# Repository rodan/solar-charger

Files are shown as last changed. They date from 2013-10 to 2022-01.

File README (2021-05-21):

12v lead-acid battery charger for 15-36V photovoltaic cells

 UNDER DEVELOPMENT

 source:       https://github.com/rodan/solar-charger 
 author:       Petre Rodan <2b4eda@subdimension.ro>
 license:      GNU GPLv3
 toolchain used: msp430-elf-gcc (Mitto Systems Limited - msp430-gcc 9.2.0.50) 9.2.0 linux

Features:
 - an MSP430F5510 uC controls all aspects of charging a 12v Pb battery
 - programming either via spy-bi-wire or usb (untested)
 - logging capability to a uSd card
 - backup 3v Li cell for keeping the RTC up-to-date
 - analog readout of battery voltage, input voltage, charge current, thermistor temperature, internal temperature
 - possibility to stop the charge if a condition is met
 - 8 status leds for verbose blinkiness
 - very low quiescent current

rev1 - used a LandStar charge controller that got replaced in rev3 with a PB137ACV ic
rev3 - 3V Li cell acts as bakup power for the uC, an SDcard is provided for logging
rev4 - SDcard is removed, 3V Li cell replaced by a 3.7v lipo + charging circuitry

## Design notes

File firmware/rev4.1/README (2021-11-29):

 source:       https://github.com/rodan/solar-charger 
 author:       Petre Rodan <2b4eda@subdimension.ro>
 license:      GNU GPLv3
 toolchain used: msp430-elf-gcc (Mitto Systems Limited - msp430-gcc 9.2.0.50) 9.2.0 linux

this firmware revision is to be used with rev4 hardware.

* How does this project work?

a photovoltaic cell and a lipo battery provide redundant power to the microcontroller. 

if the PV voltage is above 6.2V (1.5s after being enabled) then it means that it can provide 4mA of current to feed the buck circuitry and it becomes the primary power for the BQ24072 powerpath IC and the entire board. otherwise the lipo 1-cell provides power to the board.

if the PV voltage is above 6.2V (1.5s after charging circuit was enabled) then it means that it can provide the ~700mW of power needed to charge the lipo cell.

a RTC-based alarm will trigger an irrigation relay once per day.

this setup described above can be reached if J1 ties VIN to the center tap, J2 is open, a jumper ties VBAT to Q3's drain (to skip the 12V charger) and the following compoments are not populated: R32, R23, R27, D2, IC1, C26, C27.

otherwise a lead-acid 12V battery can also be charged. this option is not currently covered by the firmware.

* Compiling the project

the toolchain used for this project is provided by TI [1]. the rest of the tools needed by the Makefile in order to compile the project are readily available in most Linux distributions.
make sure to 'git clone' the msp430 reference libraries [2] (or provide a symlink to them) to /opt/atlas430

use the following commands:

 ln -s "/FIXTHIS/reference_libs_msp430" /opt/atlas430

 make
    builds the entire project with the MSP430F5510 target. all the resulting objects and the elf binary will be inside the './build/MSP430F5510' subdirectory

 make install
    takes ./build/MSP430F5510/main.elf and tries to flash it. this needs the mspdebug application, an ezfet-1.2 or msp-fet programmer connected to the target board.

 make scan-build
    optional static scan provided by Clang (if installed)

 make cppcheck
    optional static scan provided by Cppcheck (if installed)

[1] https://www.ti.com/tool/MSP430-GCC-OPENSOURCE
[2] https://github.com/rodan/atlas430

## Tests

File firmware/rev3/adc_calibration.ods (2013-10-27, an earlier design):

 | 22.7dC ambient
Port 6.0
 | vin | vsense | adc | vref | (vin/vsense)*100/1023
 | 5.013 | 0.691 | 294 | 2.4044 | 0.7092
 | 6.06 | 0.8372 | 351 | 2.4400 | 0.7076
 | 7.015 | 0.9676 | 407 | 2.4321 | 0.7087
 | 8.03 | 1.108 | 466 | 2.4324 | 0.7084
 | 9.016 | 1.2439 | 522 | 2.4378 | 0.7085
 | 10.025 | 1.3833 | 580 | 2.4399 | 0.7084
 | 11.03 | 1.5228 | 639 | 2.4379 | 0.7080
 | 12.001 | 1.656 | 695 | 2.4375 | 0.7084
 | 13.04 | 1.8 | 755 | 2.4389 | 0.7082
 | 14.07 | 1.9432 | 816 | 2.4361 | 0.7078
 | 15.02 | 2.073 | 870 | 2.4376 | 0.7083
 | 16.08 | 2.22 | 932 | 2.4368 | 0.7080
mean values |  |  |  | 2.4343 | 0.7083
 |  |  | VREF_2_5_6_0 | 2.4343
 |  |  | DIV_BAT | 0.7083
Port 6.1
 | vin | vsense | adc | vref | (vin/vsense)*100/1023
 | 5.013 | 0.4884 | 206 | 2.4254 | 1.0033
 | 6.06 | 0.5902 | 246 | 2.4544 | 1.0037
 | 7.015 | 0.6826 | 285 | 2.4502 | 1.0046
 | 8.03 | 0.7817 | 326 | 2.4530 | 1.0042
 | 9.016 | 0.8775 | 365 | 2.4594 | 1.0044
 | 10.025 | 0.9758 | 407 | 2.4527 | 1.0043
 | 11.03 | 1.074 | 448 | 2.4525 | 1.0039
 | 12.001 | 1.1679 | 487 | 2.4533 | 1.0045
 | 13.04 | 1.2696 | 529 | 2.4552 | 1.0040
 | 14.07 | 1.3707 | 571 | 2.4557 | 1.0034
 | 15.02 | 1.4625 | 609 | 2.4567 | 1.0039
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

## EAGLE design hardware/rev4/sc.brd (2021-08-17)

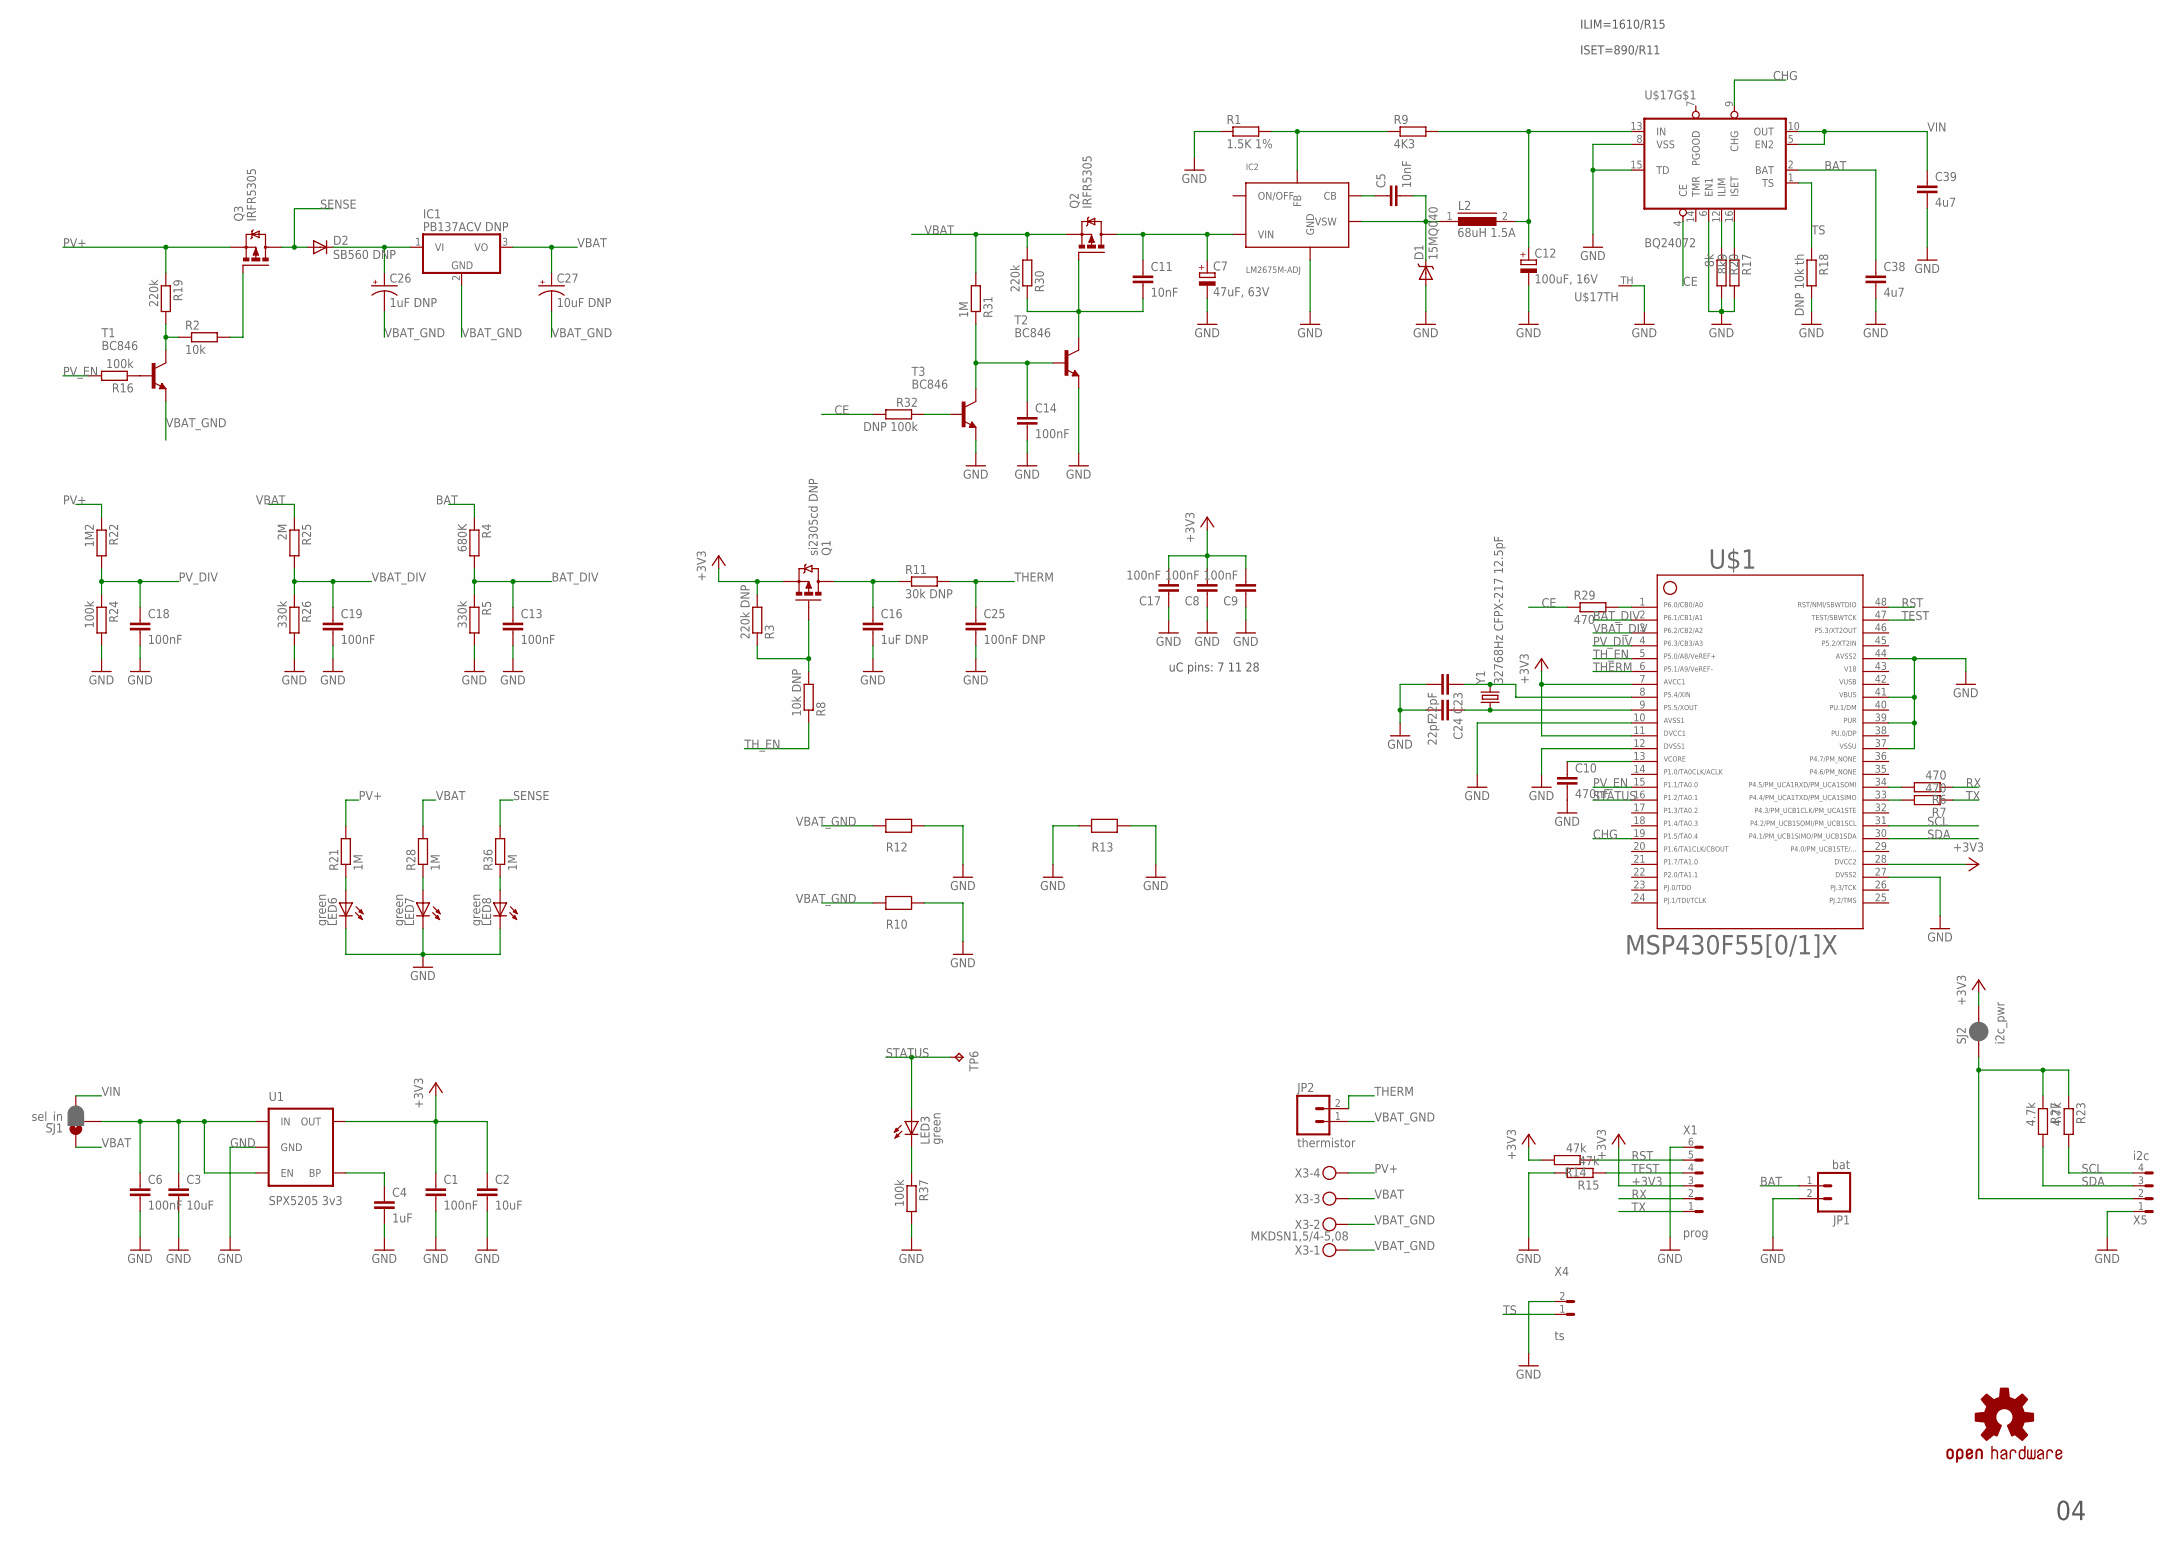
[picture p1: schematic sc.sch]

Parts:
C1, C6, C8, C9, C13, C14, C17, C18, C19: 100nF; C0805
C2, C3: 10uF; C1206
C4: 1uF; C0805
C5, C11: 10nF; C0805
C7: 47uF, 63V; PANASONIC_F
C10: 470nF; C0805
C12: 100uF, 16V; PANASONIC_D
C16: 1uF DNP; C0805
C23, C24: 22pF; C0805
C25: 100nF DNP; C0805
C26: 1uF DNP; PANASONIC_D
C27: 10uF DNP; PANASONIC_D
C38, C39: 4u7; C1206
D1: 15MQ040; SMA-DIODE
D2: SB560 DNP; C1702-05
IC1: PB137ACV DNP; TO220V
IC2: LM2675M-ADJ; SO-08
JP1: bat; 1X02
JP2: thermistor; 1X02
L2: 68uH 1.5A; DR125
LED3: green; CHIPLED_0805
LED6, LED7, LED8: green; CHIP-LED0805
Q1: si2305cd DNP; SOT23-3_POWER@1
Q2, Q3: IRFR5305; D-PAK_TO252AA
R1: 1.5K 1%; R0805W
R2: 10k; R0805W
R3: 220k DNP; R0805W
R4: 680K; R0805W
R5, R26: 330k; R0805W
R6, R7, R29: 470; R0805W
R8: 10k DNP; R0805W
R9: 4K3; R0805W
R10, R12, R13: 0R_0805; R0805W
R11: 30k DNP; R0805W
R14, R15: 47k; R0805W
R16, R24, R37: 100k; R0805W
R17: 8k9; R0805W
R18: DNP 10k th; R0805W
R19, R30: 220k; R0805W
R20: 8k; R0805W
R21, R28, R31, R36: 1M; R0805W
R22: 1M2; R0805W
R23, R27: 4.7k; R0805W
R25: 2M; R0805W
R32: DNP 100k; R0805W
SJ1: sel_in; PAD-JUMPER-3-2OF3_NC_BY_PASTE_YES_SILK_FULL_BOX
SJ2: i2c_pwr; PAD-JUMPER-2-NC_BY_PASTE_YES_SILK
T1, T2, T3: BC846; SOT23
TP6: TPTP12R; TP12R
U1: SPX5205 3v3; SOT23-5
U$1: F55[0/1]X---PT48; PT48
U$7: OSHW-LOGOM; OSHW-LOGO-M
U$17: BQ24072; S-PVQFN-N16
X1: prog; 0530480610
X3: MKDSN1,5/4-5,08
X4: ts; 0530480210
X5: i2c; 0530480401
Y1: 32768Hz CFPX-217 12.5pF; CRYSTAL-SMD-3.2X1.5

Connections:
42: U$1.42
43: U$1.43
46: U$1.46
+3V3: C1.1, C2.1, C8.2, C9.2, C17.2, Q1.2 (S), R3.2, R14.2, SJ2.2, U1.5 (OUT), U$1.7, U$1.11, U$1.28, X1.3 (4)
BAT: C38.1, JP1.1, R4.1, U$17.2 (BAT)
BAT_DIV: C13.1, R4.2, R5.1, U$1.2
CE: R29.1, R32.2, U$17.4 (CE)
CHG: U$1.19, U$17.9 (CHG)
GND: C1.2, C2.2, C3.2, C4.2, C6.2, C7.-, C8.1, C9.1, C10.2, C12.-, C13.2, C14.2, C16.2, C17.1, C18.2, C19.2, C23.2, C24.2, C25.2, C38.2, C39.2, D1.A, IC2.6 (GND), JP1.2, LED6.C, LED7.C, LED8.C, R1.1, R5.2, R10.2, R12.2, R13.1, R13.2, R15.2, R17.2, R18.2, R20.2, R24.2, R26.2, R37.2, T2.2 (E), T3.2 (E), U1.2 (GND), U$1.10, U$1.12, U$1.27, U$1.37, U$1.39, U$1.41, U$1.44, U$17.6 (EN1), U$17.8 (VSS), U$17.15 (TD), U$17.TH, X1.6 (1), X4.2 (1), X5.1 (4)
unnamed: C16.1, Q1.3 (D), R11.1
unnamed: C4.1, U1.4 (BP)
unnamed: R16.1, T1.1 (B)
unnamed: IC2.4 (FB), R1.2, R9.1
unnamed: R2.1, R19.2, T1.3 (C)
unnamed: C10.1, U$1.13
unnamed: C3.1, C6.1, SJ1.2, U1.1 (IN), U1.3 (EN)
unnamed: C26.+, D2.C, IC1.1 (VI)
unnamed: C5.2, D1.C, IC2.8 (VSW), L2.1
unnamed: C5.1, IC2.1 (CB)
unnamed: R6.2, U$1.34
unnamed: LED6.A, R21.1
unnamed: R7.2, U$1.33
unnamed: Q1.1 (G), R3.1, R8.2
unnamed: C12.+, L2.2, R9.2, U$17.13 (IN)
unnamed: C11.2, Q2.1 (G), R30.1, T2.3 (C)
unnamed: R23.1, R27.1, SJ2.1, X5.2 (3)
unnamed: LED7.A, R28.1
unnamed: R29.2, U$1.1
unnamed: C14.1, R31.1, T2.1 (B), T3.3 (C)
unnamed: R32.1, T3.1 (B)
unnamed: LED8.A, R36.1
unnamed: C24.1, U$1.9, Y1.P$1 (1)
unnamed: C23.1, U$1.8, Y1.P$2 (2)
unnamed: Q3.1 (G), R2.2
unnamed: R17.1, U$17.16 (ISET)
unnamed: R20.1, U$17.12 (ILIM)
unnamed: LED3.C, R37.1
unnamed: C7.+, C11.1, IC2.7 (VIN), Q2.4 (D)
PV+: Q3.3 (S), R19.1, R21.2, R22.1, X3.4
PV_DIV: C18.1, R22.2, R24.1, U$1.4
PV_EN: R16.2, U$1.15
RST: R14.1, U$1.48, X1.5 (2)
RX: R6.1, X1.2 (5)
SCL: R23.2, U$1.31, X5.4 (1)
SDA: R27.2, U$1.30, X5.3 (2)
SENSE: D2.A, Q3.4 (D), R36.2
STATUS: LED3.A, TP6.TP, U$1.16
TEST: R15.1, U$1.47, X1.4 (3)
THERM: C25.1, JP2.2, R11.2, U$1.6
TH_EN: R8.1, U$1.5
TS: R18.1, U$17.1 (TS), X4.1 (2)
TX: R7.1, X1.1 (6)
VBAT: C27.+, IC1.3 (VO), Q2.3 (S), R25.1, R28.2, R30.2, R31.2, SJ1.1, X3.3
VBAT_DIV: C19.1, R25.2, R26.1, U$1.3
VBAT_GND: C26.-, C27.-, IC1.2 (GND), JP2.1, R10.1, R12.1, T1.2 (E), X3.1, X3.2
VIN: C39.1, SJ1.3, U$17.5 (EN2), U$17.10 (OUT)

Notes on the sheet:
uC pins: 7 11 28
ILIM=1610/R15
ISET=890/R11

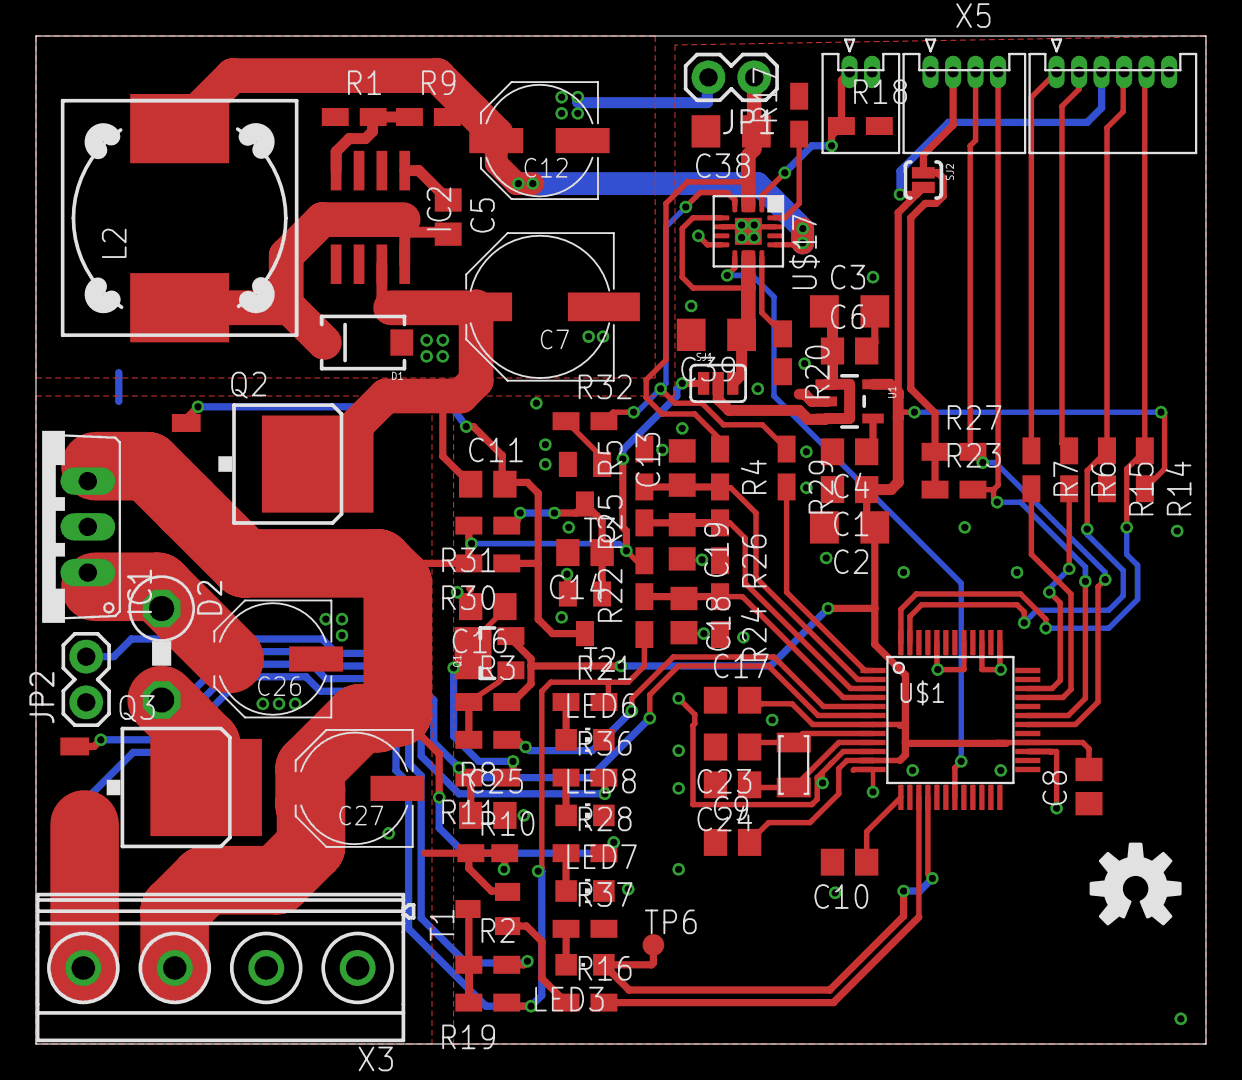
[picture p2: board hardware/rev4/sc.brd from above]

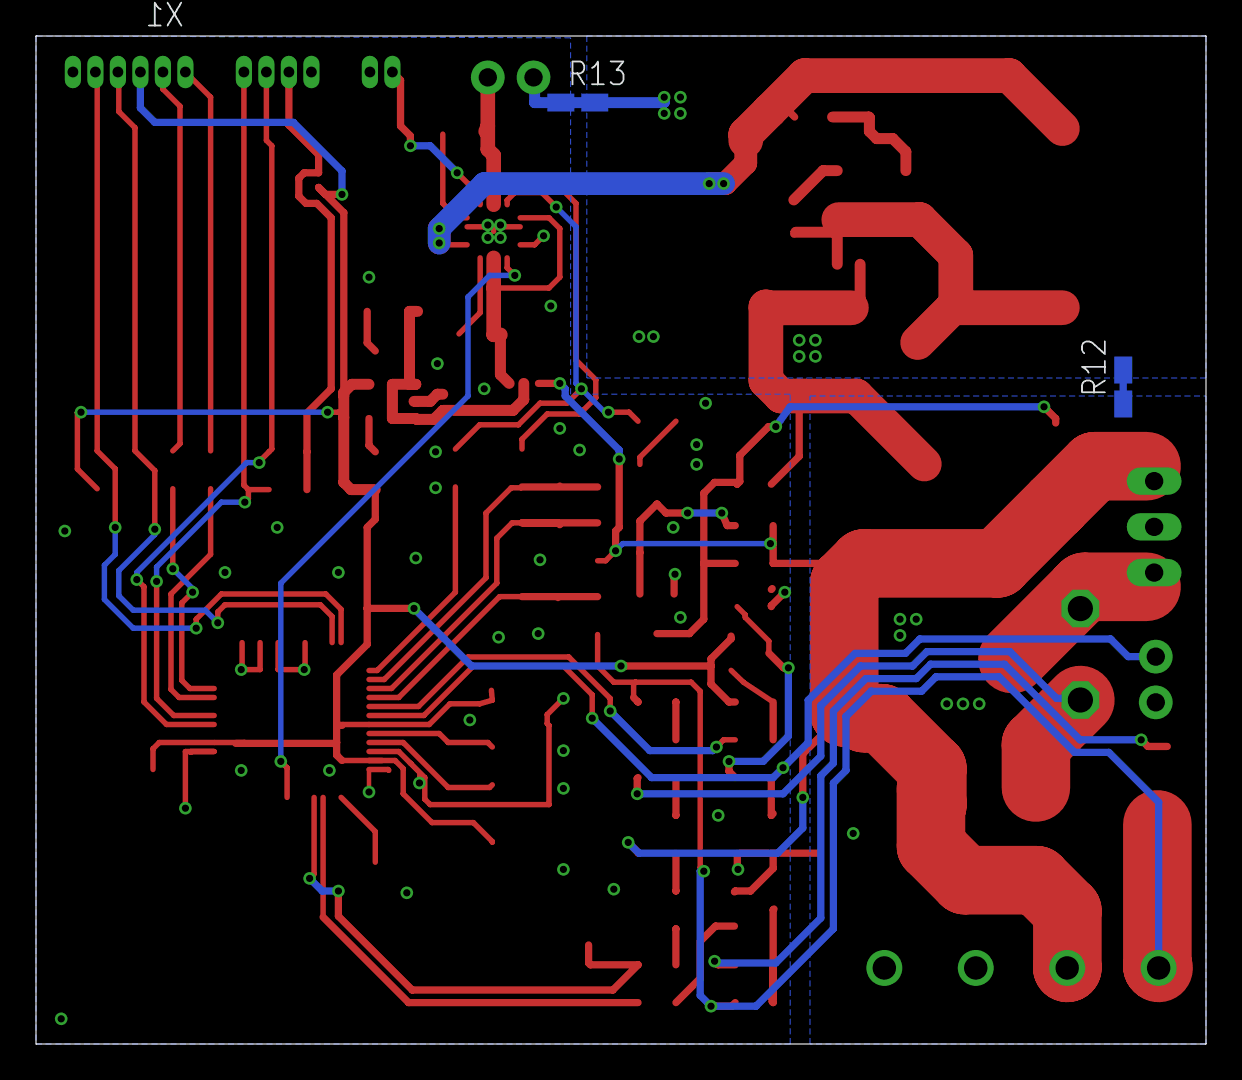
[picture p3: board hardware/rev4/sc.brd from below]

Board: 2 copper layers, 65.0 x 56.0 mm, 88 parts (2 on the bottom side), 53 nets.

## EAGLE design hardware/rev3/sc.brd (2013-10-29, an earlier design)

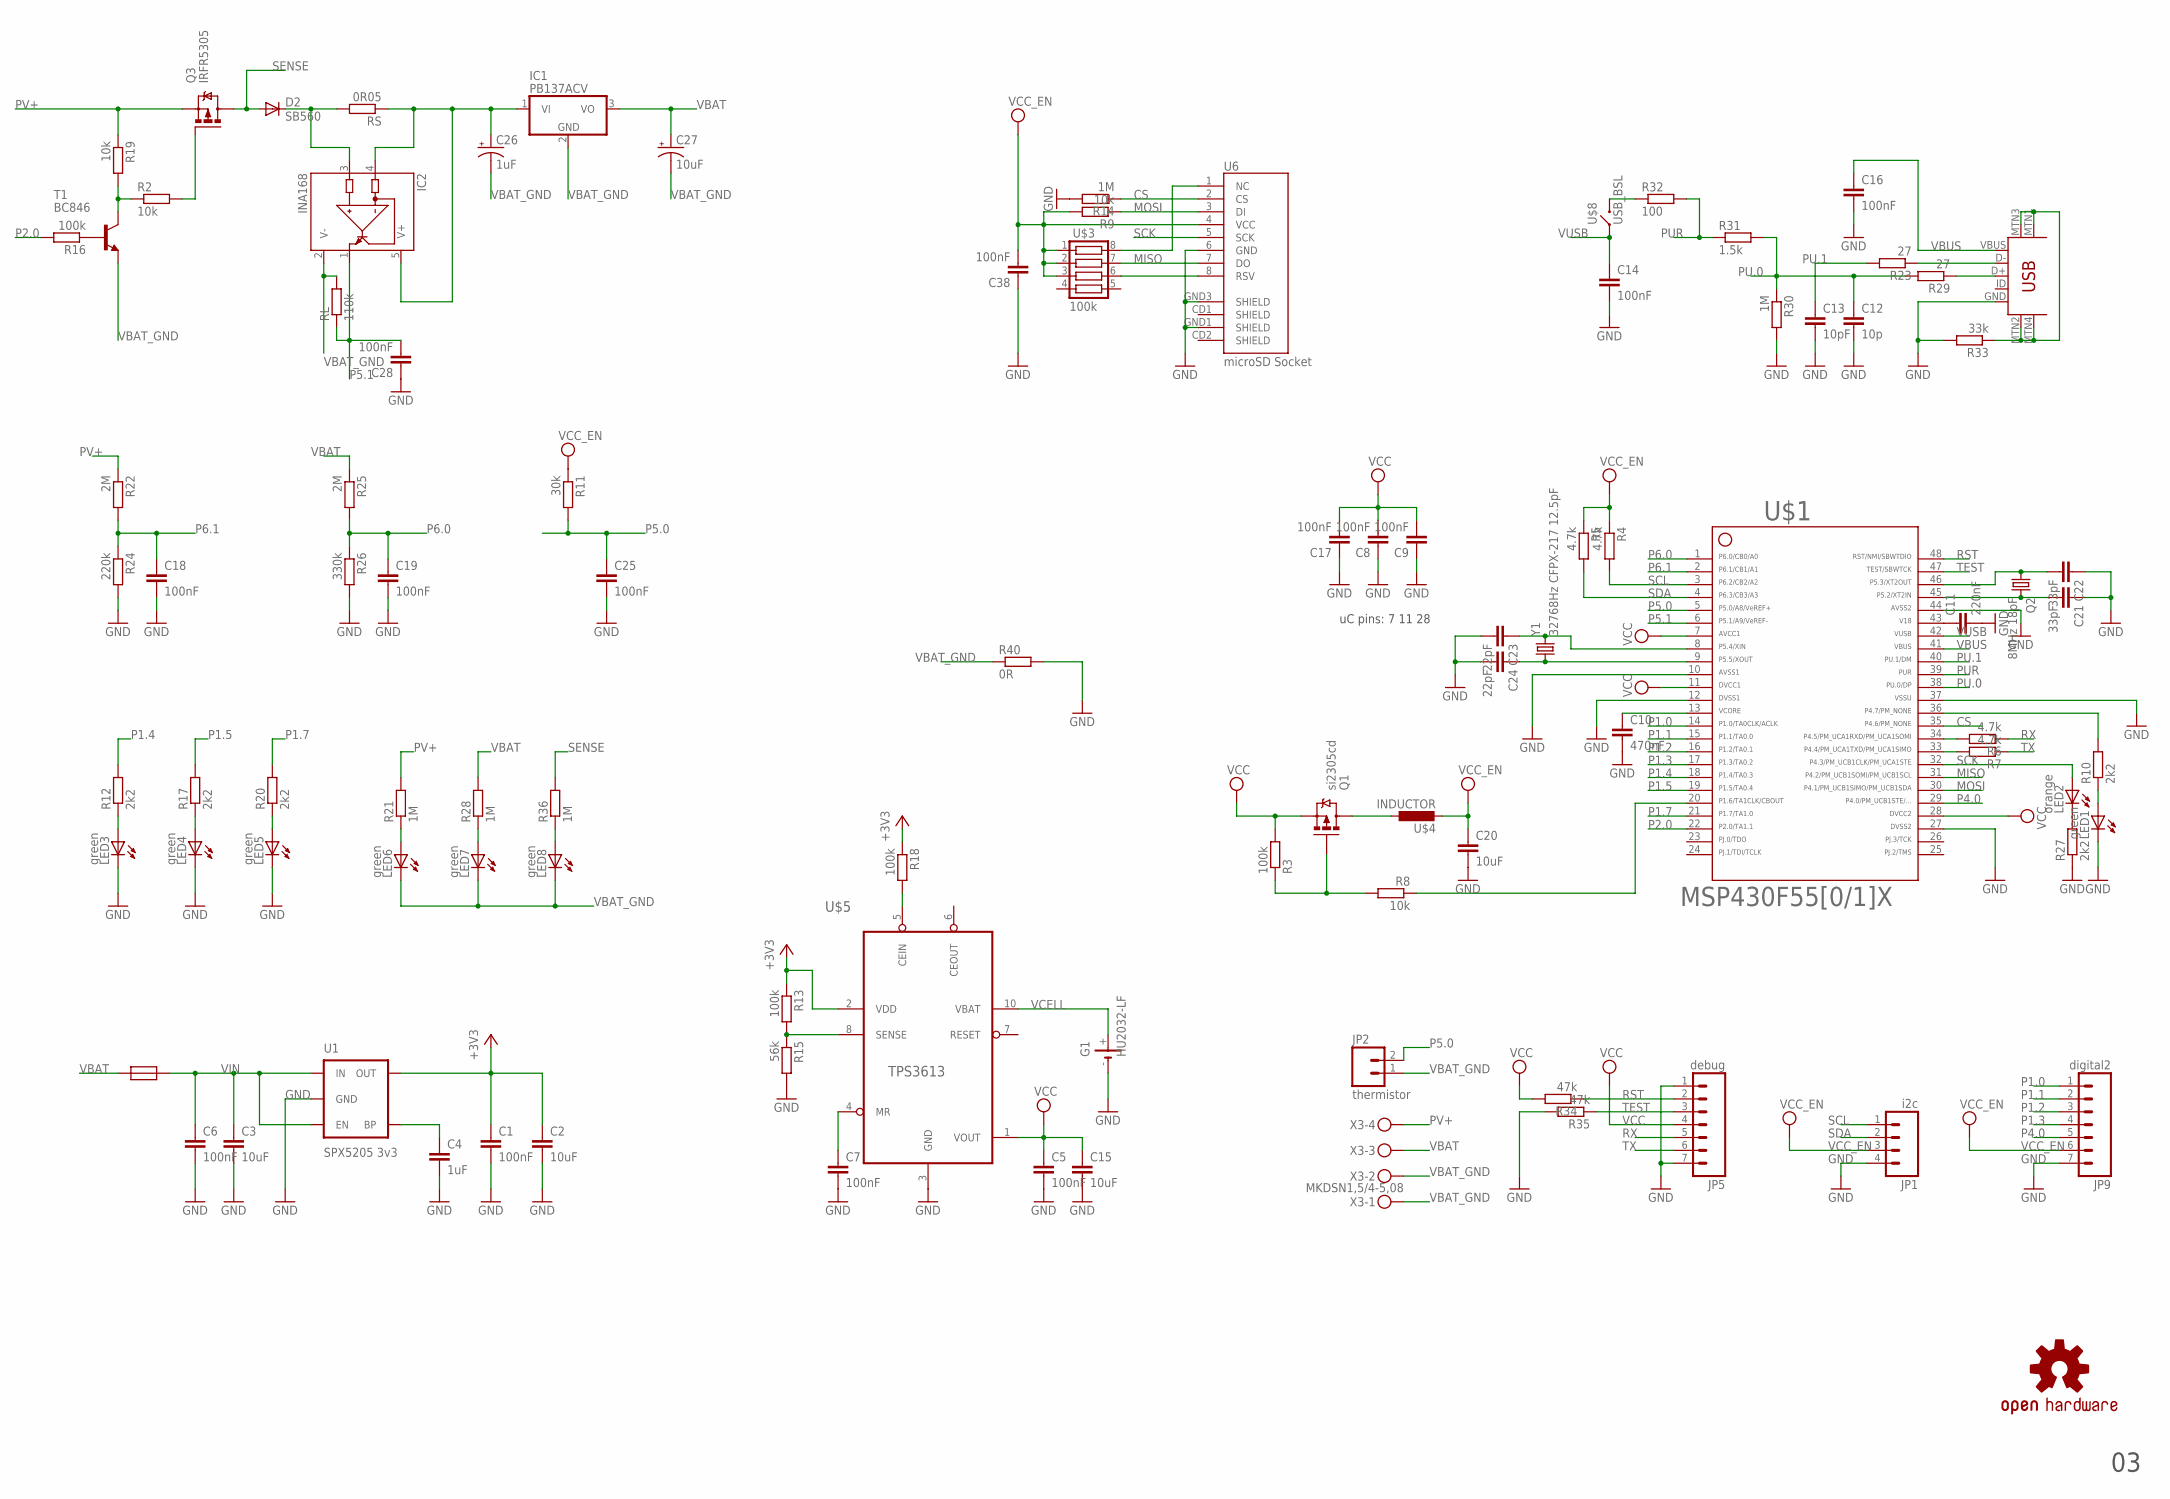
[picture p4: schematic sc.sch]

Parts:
C1, C5, C6, C7, C8, C9, C14, C16, C17, C18, C19, C25, C28, C38: 100nF; C0805
C2, C3, C15, C20: 10uF; C1206
C4: 1uF; C0805
C10: 470nF; C0805
C11: 220nF; C0805
C12: 10p; C0805
C13: 10pF; C0805
C21, C22: 33pF; C0805
C23, C24: 22pF; C0805
C26: 1uF; PANASONIC_D
C27: 10uF; PANASONIC_D
D2: SB560; C1702-05
G1: HU2032-LF
IC1: PB137ACV; TO220V
IC2: INA168; SOT23-5
JP1: i2c; 1X04
JP2: thermistor; 1X02
JP5: debug; 1X07
JP9: digital2; 1X07
LED1, LED3, LED4, LED5, LED6, LED7, LED8: green; CHIP-LED0805
LED2: orange; CHIP-LED0805
Q1: si2305cd; SOT23-3_POWER
Q2: 8MHz 18pF; CRYSTAL_5X3.2
Q3: IRFR5305; D-PAK_TO252AA
R2, R8, R9, R19: 10k; R0805W
R3, R13, R16, R18: 100k; R0805W
R4, R5, R6, R7: 4.7k; R0805W
R10, R12, R17, R20, R27: 2k2; R0805W
R11: 30k; R0805W
R14, R21, R28, R30, R36: 1M; R0805W
R15: 56k; R0805W
R22, R25: 2M; R0805W
R23, R29: 27; R0805W
R24: 220k; R0805W
R26: 330k; R0805W
R31: 1.5k; R0805W
R32: 100; R0805W
R33: 33k; R0805W
R34, R35: 47k; R0805W
R40: 0R; R0805W
RL: 110k; R0805W
RS: 0R05; TO220ACS
T1: BC846; SOT23
U1: SPX5205 3v3; SOT23-5
U6: microSD Socket; MICRO-SD-SOCKET-PP
U$1: F55[0/1]X---PT48; PT48
U$2: RESETTABLE; 1210
U$3: 100k; YC164
U$4: INDUCTOR; L0805W
U$5: TPS3613; MSOP_10P
U$6: USB-MINIB-5PIN; USB-MINIB
U$7: OSHW-LOGOM; OSHW-LOGO-M
U$8: USB_BSL; 6X3.5_TACTILE_SW
X3: MKDSN1,5/4-5,08
Y1: 32768Hz CFPX-217 12.5pF; CRYSTAL-SMD-3.2X1.5

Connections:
+3V3: C1.1, C2.1, R13.1, R18.1, U1.5 (OUT), U$5.2 (VDD)
CS: R14.1, U6.2 (CS), U$1.35
EN: R8.1, U$1.20
GND: C1.2, C2.2, C3.2, C4.2, C5.2, C6.2, C7.2, C8.1, C9.1, C10.2, C11.2, C12.2, C13.2, C14.2, C15.2, C16.2, C17.1, C18.2, C19.2, C20.2, C21.1, C22.1, C23.2, C24.2, C25.2, C28.1, C38.1, G1.-, JP1.4, JP5.1, JP5.7, JP9.7, LED1.C, LED3.C, LED4.C, LED5.C, R14.2, R15.2, R24.2, R26.2, R27.1, R30.2, R33.2, R35.2, R40.2, U1.2 (GND), U6.6 (GND), U6.GND1 (SHIELD), U6.GND3 (SHIELD), U$1.10, U$1.12, U$1.27, U$1.37, U$1.44, U$5.3 (GND), U$6.GND
LED: R10.2, U$1.36
MISO: U6.7 (DO), U$1.31, U$3.7
MOSI: R9.1, U6.3 (DI), U$1.30
unnamed: LED1.A, R10.1
unnamed: C4.1, U1.4 (BP)
unnamed: R16.1, T1.1 (B)
unnamed: U6.1 (NC), U$3.8
unnamed: R2.1, R19.2, T1.3 (C)
unnamed: C10.1, U$1.13
unnamed: C11.1, U$1.43
unnamed: LED3.A, R12.1
unnamed: C26.+, IC1.1 (VI), IC2.4 (IN-), IC2.5 (V+), RS.A (1)
unnamed: R6.2, U$1.34
unnamed: LED6.A, R21.1
unnamed: R7.2, U$1.33
unnamed: Q1.1 (G), R3.1, R8.2
unnamed: LED4.A, R17.1
unnamed: LED5.A, R20.1
unnamed: C22.2, Q2.P$1 (1), U$1.46
unnamed: LED7.A, R28.1
unnamed: R13.2, R15.1, U$5.8 (SENSE)
unnamed: C7.1, U$5.4 (MR)
unnamed: R18.2, U$5.5 (CEIN)
unnamed: R29.1, U$6.D+
unnamed: C21.2, Q2.P$2 (2), U$1.45
unnamed: LED8.A, R36.1
unnamed: C24.1, U$1.9, Y1.P$1 (1)
unnamed: C23.1, U$1.8, Y1.P$2 (2)
unnamed: U6.8 (RSV), U$3.6
unnamed: Q3.1 (G), R2.2
unnamed: R23.1, U$6.D-
unnamed: D2.C, IC2.3 (IN+), RS.C (2)
unnamed: R32.1, U$8.2
unnamed: R33.1, U$6.MTN1 (MTN2), U$6.MTN2 (MTN3), U$6.MTN3 (MTN1), U$6.MTN4
unnamed: Q1.3 (D), U$4.1
unnamed: LED2.C, R27.2
P1.0: JP9.1, U$1.14
P1.1: JP9.2, U$1.15
P1.2: JP9.3, U$1.16
P1.3: JP9.4, U$1.17
P1.4: R12.2, U$1.18
P1.5: R17.2, U$1.19
P1.7: R20.2, U$1.21
P2.0: R16.2, U$1.22
P4.0: JP9.5, U$1.29
P5.0: C25.1, JP2.2, R11.2, U$1.5
P5.1: C28.2, IC2.1 (OUT), RL.1, U$1.6
P6.0: C19.1, R25.2, R26.1, U$1.1
P6.1: C18.1, R22.2, R24.1, U$1.2
PU.0: C12.1, R29.2, R30.1, R31.2, U$1.38
PU.1: C13.1, R23.2, U$1.40
PUR: R31.1, R32.2, U$1.39
PV+: Q3.3 (S), R19.1, R21.2, R22.1, X3.4
RST: JP5.2, R34.1, U$1.48
RX: JP5.5, R6.1
SCK: LED2.A, U6.5 (SCK), U$1.32
SCL: JP1.1, R4.2, U$1.3
SDA: JP1.2, R5.2, U$1.4
SENSE: D2.A, Q3.4 (D), R36.2
TEST: JP5.3, R35.1, U$1.47
TX: JP5.6, R7.1
VBAT: C27.+, IC1.3 (VO), R25.1, R28.2, U$2.P$1, X3.3
VBAT_GND: C26.-, C27.-, IC1.2 (GND), IC2.2 (V-), JP2.1, LED6.C, LED7.C, LED8.C, R40.1, RL.2, T1.2 (E), X3.1, X3.2
VBUS: C16.1, U$1.41, U$6.VBUS
VCC: C5.1, C8.2, C9.2, C15.1, C17.2, JP5.4, Q1.2 (S), R3.2, R34.2, U$1.7, U$1.11, U$1.28, U$5.1 (VOUT)
VCC_EN: C20.1, C38.2, JP1.3, JP9.6, R4.1, R5.1, R9.2, R11.1, U6.4 (VCC), U$3.1, U$3.2, U$3.3, U$4.2
VCELL: G1.+, U$5.10 (VBAT)
VIN: C3.1, C6.1, U1.1 (IN), U1.3 (EN), U$2.P$2
VUSB: C14.1, U$1.42, U$8.1

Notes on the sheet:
uC pins: 7 11 28

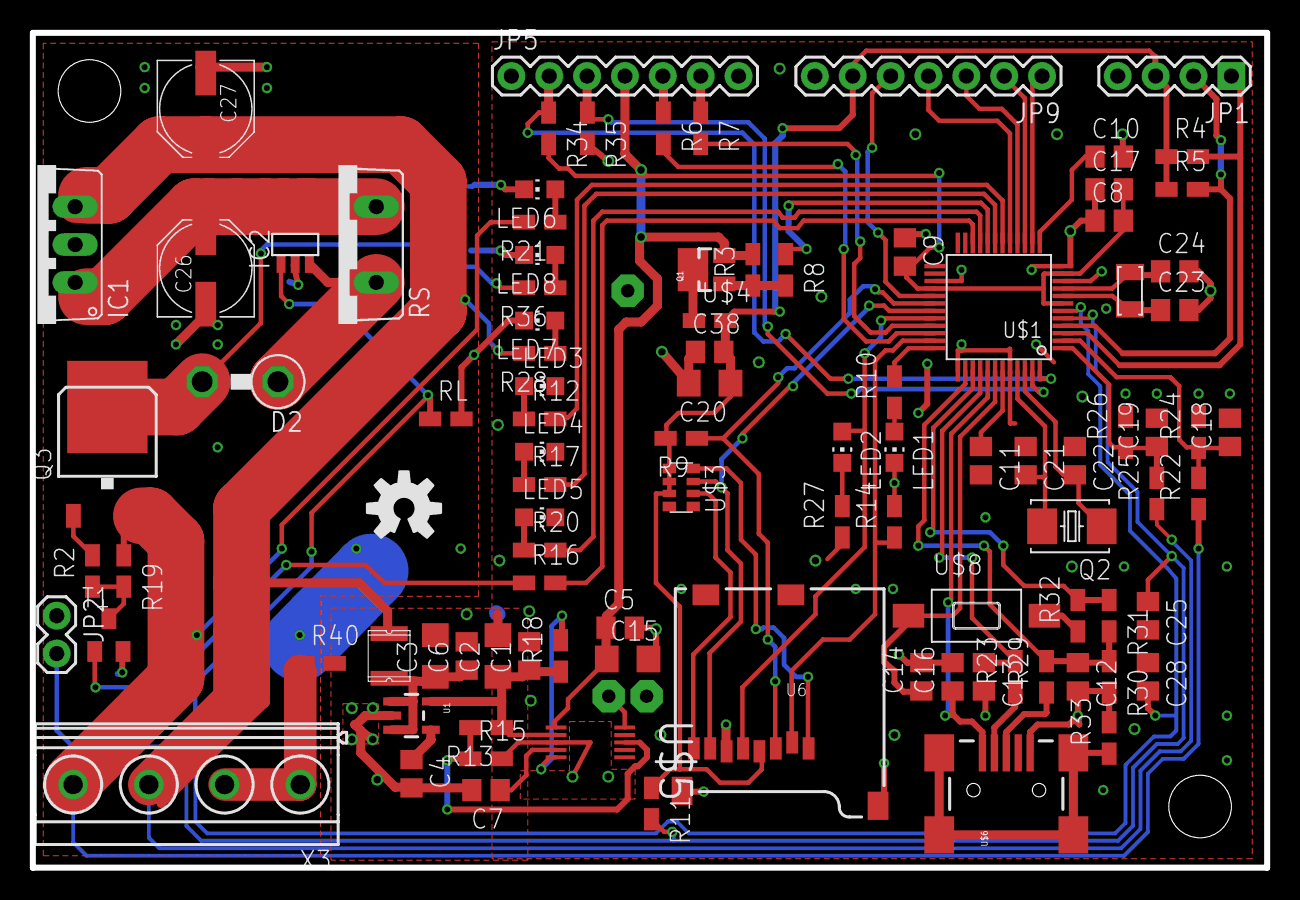
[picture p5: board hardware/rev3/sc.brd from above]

Board: 2 copper layers, 82.8 x 56.0 mm, 99 parts (1 on the bottom side), 73 nets.

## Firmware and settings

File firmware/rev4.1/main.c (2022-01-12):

/*
    program that tests the functionality of the EUSCI A0 UART 

    tweak the baud rate in config.h
*/

#include <msp430.h>
#include <stdio.h>
#include <string.h>

#include "proj.h"
#include "driverlib.h"
#include "glue.h"
#include "ui.h"
#include "adc.h"
#include "rtc.h"
#include "pwr_mng.h"
#include "rtca_now.h"
#include "timer_a0.h"
#include "timer_a2.h"

uint8_t port1_last_event;
struct adc_conv adc;
uart_descriptor bc; // backchannel uart interface

void port_init(void)
{
    // analog inputs
    P5SEL |= BIT1;
    P6SEL |= BIT1 | BIT2 | BIT3;

    // digital outputs
    P1DIR |= BIT1 | BIT2;
    P5DIR |= BIT0;
    P4DIR |= BIT2;
    P6DIR |= BIT0;

    // digital inputs
    P1DIR &= ~BIT5;
    // enable pullup resistor
    P1REN |= BIT5;
    P1OUT |= BIT5;

    // IRQ triggers on rising edge
    P1IES &= ~BIT5;
    // Reset IRQ flags
    P1IFG &= ~BIT5;
    // Enable button interrupts
    P1IE |= BIT5;
}

static void uart_rx_irq(uint32_t msg)
{
    parse_user_input();
    uart_set_eol(&bc);
}

void check_events(void)
{
    uint16_t msg = SYS_MSG_NULL;
    uint16_t ev;

    // RTC
    ev = rtca_get_event();
    if (ev) {
        if (rtca_get_event() & RTCA_EV_MINUTE) {
            msg |= SYS_MSG_RTC_MINUTE;
        }
        if (rtca_get_event() & RTCA_EV_ALARM) {
            msg |= SYS_MSG_RTC_ALARM;
        }
        rtca_rst_event();
    }
    // uart RX
    if (uart_get_event(&bc) == UART_EV_RX) {
        msg |= SYS_MSG_UART1_RX;
        uart_rst_event(&bc);
    }
    // timer_a2
    ev = timer_a2_get_event();
    if (ev) {
        if (ev & TIMER_A2_EVENT_CCR1) {
            msg |= SYS_MSG_TIMERA2_CCR1;
        }
        timer_a2_rst_event();
    }
    // timer_a2-based scheduler
    ev = timer_a2_get_event_schedule();
    if (ev) {
        if (timer_a2_get_event_schedule() & (1 << SCHEDULE_LED_ON)) {
            msg |= SYS_MSG_SCH_LED_ON;
        }
        if (timer_a2_get_event_schedule() & (1 << SCHEDULE_LED_OFF)) {
            msg |= SYS_MSG_SCH_LED_OFF;
        }
        if (timer_a2_get_event_schedule() & (1 << SCHEDULE_RELAY_OFF)) {
            msg |= SYS_MSG_SCH_RELAY_OFF;
        }
        if (timer_a2_get_event_schedule() & (1 << SCHEDULE_CHECK_PV)) {
            msg |= SYS_MSG_SCH_CHECK_PV;
        }
        if (timer_a2_get_event_schedule() & (1 << SCHEDULE_REFRESH_VIS)) {
            msg |= SYS_MSG_SCH_REFRESH_VIS;
        }

        timer_a2_rst_event_schedule();
    }
    // p1.5 rising edge trigger
    if (port1_last_event) {
        msg |= SYS_MSG_P1IFG;
        port1_last_event = 0;
    }

    eh_exec(msg);
}

static void scheduler_handler(uint32_t msg)
{
    timer_a2_scheduler_handler();
}

void led_on_handler(uint32_t msg)
{
    struct pwr_mng_blinky *blinky = pwr_mng_bliky_p();
    st_on;
    timer_a2_set_trigger_slot(SCHEDULE_LED_OFF, systime() + blinky->on, TIMER_A2_EVENT_ENABLE);
}

static void led_off_handler(uint32_t msg)
{
    struct pwr_mng_blinky *blinky = pwr_mng_bliky_p();
    st_off;
    if (blinky->off) {
        timer_a2_set_trigger_slot(SCHEDULE_LED_ON, systime() + blinky->off, TIMER_A2_EVENT_ENABLE);
    }
}

static void relay_off_handler(uint32_t msg)
{
    st_off;
    relay_off;
}

static void rtc_alarm(uint32_t msg)
{
    relay_on;
    timer_a2_set_trigger_slot(SCHEDULE_RELAY_OFF, systime() + 30, TIMER_A2_EVENT_ENABLE);
}

void update_adc(void)
{
    uint32_t tmp;
    //sig0_on;
    adc10_read(1, &adc.lipo, REFVSEL_0);
    //adc10_read(2, &q_vbat, REFVSEL_0);
    adc10_read(3, &adc.pv, REFVSEL_0);
    //adc10_read(9, &q_th, REFVSEL_0);
    adc10_read(10, &adc.t_internal, REFVSEL_0);
    adc10_halt();
    //sig0_off;

    tmp = (uint32_t) ((uint32_t) adc.lipo.counts_calib * (uint32_t) LIPO_SLOPE) >> 12;
    adc.lipo.conv = (uint16_t) tmp;
    adc.lipo.calib = adc.lipo.conv;     // FIXME

    tmp = (uint32_t) ((uint32_t) adc.pv.counts_calib * (uint32_t) PV_SLOPE) >> 12;
    adc.pv.conv = (uint16_t) tmp;
    adc.pv.calib = adc.pv.conv; // FIXME
}

static void check_pv_handler(uint32_t msg)
{
    update_adc();
    if (pwr_mng_check_pv(&adc) == PWR_PV_CHECK_RERUN) {
        timer_a2_set_trigger_slot(SCHEDULE_CHECK_PV, systime() + 150, TIMER_A2_EVENT_ENABLE);
    }
}

static void refresh_vis_handler(uint32_t msg)
{
    pwr_mng_refresh_vis(&adc);
}

static void main_loop(uint32_t msg)
{
    update_adc();
    pwr_mng(&adc);
    timer_a2_set_trigger_slot(SCHEDULE_CHECK_PV, systime() + 150, TIMER_A2_EVENT_ENABLE);
    timer_a2_set_trigger_slot(SCHEDULE_REFRESH_VIS, systime() + 350, TIMER_A2_EVENT_ENABLE);

#ifdef CONFIG_DEBUG
    char itoa_buf[CONV_BASE_10_BUF_SZ];

    uart_print(&bc, "lipo ");
    uart_print(&bc, _utoa(itoa_buf, adc.lipo.counts));
    uart_print(&bc, " ");
    uart_print(&bc, _utoa(itoa_buf, adc.lipo.counts_calib));
    uart_print(&bc, " ");
    uart_print(&bc, _utoa(itoa_buf, adc.lipo.conv));
    uart_print(&bc, ", pv ");
    uart_print(&bc, _utoa(itoa_buf, adc.pv.counts));
    uart_print(&bc, " ");
    uart_print(&bc, _utoa(itoa_buf, adc.pv.counts_calib));
    uart_print(&bc, " ");
    uart_print(&bc, _utoa(itoa_buf, adc.pv.conv));
    uart_print(&bc, ", tint ");
    uart_print(&bc, _utoa(itoa_buf, adc.t_internal.counts));
    uart_print(&bc, " ");
    uart_print(&bc, _utoa(itoa_buf, adc.t_internal.conv));
    uart_print(&bc, "\r\n");
#endif

}

int main(void)
{
    struct rtca_tm t;

    // watchdog triggers after 25sec when not cleared
#ifdef USE_WATCHDOG
    WDTCTL = WDTPW + WDTIS__512K + WDTSSEL__ACLK + WDTCNTCL;
#else
    WDTCTL = WDTPW + WDTHOLD;
#endif
    msp430_hal_init(HAL_GPIO_DIR_OUTPUT | HAL_GPIO_OUT_LOW);
    port_init();
    st_on;

    clock_pin_init();
    clock_init();

    rtca_init();
    //t.hour = COMPILE_HOUR;
    //t.min = COMPILE_MIN + 2;
    t.hour = 10;
    t.min = 0;
    rtca_set_alarm(&t, AE_MIN | AE_HOUR);
    rtca_enable_alarm();

    bc.baseAddress = USCI_A1_BASE;
    bc.baudrate = BAUDRATE_57600;
    uart_pin_init(&bc);
    uart_init(&bc);
#if defined UART_RX_USES_RINGBUF
    uart_set_rx_irq_handler(&bc, uart_rx_ringbuf_handler);
#else
    uart_set_rx_irq_handler(&bc, uart_rx_simple_handler);
#endif

    timer_a0_init();
    timer_a2_init();

    pwr_mng_init();

    eh_init();
    eh_register(&main_loop, SYS_MSG_RTC_MINUTE);
    eh_register(&rtc_alarm, SYS_MSG_RTC_ALARM);
    eh_register(&uart_rx_irq, SYS_MSG_UART1_RX);
    //eh_register(&main_loop, SYS_MSG_P1IFG);
    eh_register(&scheduler_handler, SYS_MSG_TIMERA2_CCR1);
    eh_register(&led_off_handler, SYS_MSG_SCH_LED_OFF);
    eh_register(&led_on_handler, SYS_MSG_SCH_LED_ON);
    eh_register(&relay_off_handler, SYS_MSG_SCH_RELAY_OFF);
    eh_register(&check_pv_handler, SYS_MSG_SCH_CHECK_PV);
    eh_register(&refresh_vis_handler, SYS_MSG_SCH_REFRESH_VIS);

    st_off;                     // init ended

    //display_menu();

    while (1) {
        // sleep
        _BIS_SR(LPM3_bits + GIE);
        __no_operation();
#ifdef USE_WATCHDOG
        WDTCTL = (WDTCTL & 0xff) | WDTPW | WDTCNTCL;
#endif
        check_events();
        check_events();
        check_events();
    }
}

// Port 1 interrupt service routine
#if defined(__TI_COMPILER_VERSION__) || defined(__IAR_SYSTEMS_ICC__)
#pragma vector=PORT1_VECTOR
__interrupt void Port_1(void)
#elif defined(__GNUC__)
__attribute__((interrupt(PORT1_VECTOR)))
void Port1_ISR(void)
#else
#error Compiler not supported!
#endif
{
    uint16_t iv = P1IFG;
    if (iv & P1IV_P1IFG5) {
        port1_last_event = BIT5;
        P1IFG &= ~P1IV_P1IFG5;
        _BIC_SR_IRQ(LPM3_bits);
    }
    P1IFG = 0;
}

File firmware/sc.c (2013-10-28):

//  sensor control board based on a MSP430F5510 uC
//   - compatible with hardware rev 03 -
//
//  author:          Petre Rodan <petre.rodan@simplex.ro>
//  available from:  https://github.com/rodan/
//  license:         GNU GPLv3

#include <stdio.h>
#include <string.h>

#include "sc.h"
#include "calib.h"
#include "drivers/sys_messagebus.h"
#include "drivers/pmm.h"
#include "drivers/rtc.h"
#include "drivers/timer_a1.h"
#include "drivers/timer_a0.h"
#include "drivers/lcd.h"
#include "drivers/uart.h"
#include "drivers/ir_remote.h"
#include "drivers/intertechno.h"
#include "drivers/serial_bitbang.h"
#include "drivers/hsc_ssc_i2c.h"
#include "drivers/sensirion.h"
#include "drivers/oled_128x64.h"
#include "drivers/diskio.h"
#include "drivers/mmc.h"
#include "drivers/adc.h"
#include "drivers/hal_sdcard.h"

// DIR is defined as "0x0001 - USB Data Response Bit" in msp430 headers
// but it's also used by fatfs
#undef DIR
#include "fatfs/ff.h"

char str_temp[64];
FATFS fatfs;
DIR dir;
FIL f;

float v_bat, v_pv, i_ch, t_th, t_int;

uint8_t last_ch_ena;
uint32_t status_last;

// acts register
// 15 14 13 12 11 10  9  8  7  6  5  4  3  2  1  0
//                                   |  |  |  |  |
//                                   |  |  |  |   --> first start
//                                   |  |  |   -----> charge stopped, batt overcharged
//                                   |  |   --------> charge stopped, pv too low
//                                   |   -----------> 
//                                    --------------> enable charging

uint16_t acts;

void die(uint8_t loc, FRESULT rc)
{
    sprintf(str_temp, "l=%d rc=%u\r\n", loc, rc);
    uart_tx_str(str_temp, strlen(str_temp));
}

#ifdef CALIBRATION
static void do_calib(enum sys_message msg)
{
    uint16_t q_bat = 0, q_pv = 0, q_t_int = 0, q_ch = 0, q_th = 0;

    opt_power_enable();
    timer_a0_delay(300000);

    adc10_read(0, &q_bat, REFVSEL_2);
    v_bat = q_bat * VREF_2_5_6_0 * DIV_BAT;
    adc10_read(1, &q_pv, REFVSEL_2);
    v_pv = q_pv * VREF_2_5_6_1 * DIV_PV;
    
    adc10_read(10, &q_t_int, REFVSEL_0);
    //t_int = ((q_t_int * VREF_1_5) / 102.3 - 6.88) * 396.8;
    t_int = 10.0 * ( q_t_int * T_INT_B + T_INT_A );

    adc10_read(9, &q_ch, REFVSEL_2);
    i_ch = 100.0 * ((q_ch * VREF_2_5_5_1 / 1023) * INA168_B + INA168_A);
    adc10_read(8, &q_th, REFVSEL_2);
    t_th = 10.0 * ((q_th * VREF_2_5_5_0 / 1023) * TH_B + TH_A);

    adc10_halt();
    opt_power_disable();

    //-21.3 | bat 1023 22.22 | pv 1023 22.22DA0
    snprintf(str_temp, 42,
             "% 2d.%1d | bat % 4d %02d.%02d | pv % 4d %02d.%02d\r\n",
             (uint16_t) t_int / 10, (uint16_t) t_int % 10, q_bat,
             (uint16_t) v_bat / 100, (uint16_t) v_bat % 100, q_pv,
             (uint16_t) v_pv / 100, (uint16_t) v_pv % 100);
    uart_tx_str(str_temp, strlen(str_temp));

    snprintf(str_temp, 42,
             "ch: % 4d %01d.%02d | th % 4d  %01d.%02d\r\n",
             q_ch, (uint16_t) i_ch / 100, (uint16_t) i_ch % 100,
             q_th, (uint16_t) t_th / 10, (uint16_t) t_th % 10);
    uart_tx_str(str_temp, strlen(str_temp));

    snprintf(str_temp, 35,
             "t_int: % 4d 30: %d, 85: %d \r\n",
             q_t_int,
             *(uint16_t *)0x1a1a, *(uint16_t *)0x1a1c);
    uart_tx_str(str_temp, strlen(str_temp));

    // blinky
    //P4OUT ^= BIT7;
}
#else
static void do_smth(enum sys_message msg)
{
    uint16_t q_bat = 0;
    uint16_t q_pv = 0, q_t_int = 0;
    uint16_t q_ch = 0, q_th = 0;
    uint32_t status;

    acts = 0;

    adc10_read(0, &q_bat, REFVSEL_2);
    v_bat = q_bat * VREF_2_5_6_0 * DIV_BAT;

    // values are multiplied by 100 for snprintf
    if (v_bat < 350) {
        // do nothing since we run on the 3v Li cell
        adc10_halt();
        return;
    } else if (v_bat > 1400) {
        charge_disable();
        acts |= BIT1;
    }

    adc10_read(1, &q_pv, REFVSEL_2);
    v_pv = q_pv * VREF_2_5_6_1 * DIV_PV;

    adc10_read(9, &q_ch, REFVSEL_2);
    i_ch = 100.0 * ((q_ch * VREF_2_5_5_1 / 1023) * INA168_B + INA168_A);

    // see temperature sensor transfer function
    // in slau208 datasheet page ~707
    adc10_read(10, &q_t_int, REFVSEL_0);
    //t_int = ((q_t_int * VREF_1_5) / 102.3 - 6.88) * 396.8;
    t_int = 10.0 * ( q_t_int * T_INT_B + T_INT_A );

    if (v_pv < 1400) {
        charge_disable();
        acts |= BIT2;
    }

    if ((v_pv > 1400) && (v_pv < 2100) && (v_bat < 1400)) {
        charge_enable();
        acts |= BIT4;
    }

    opt_power_enable();
    timer_a0_delay(100000);

    adc10_read(8, &q_th, REFVSEL_2);
    t_th = 10.0 * ((q_th * VREF_2_5_5_0 / 1023) * TH_B + TH_A);

    adc10_halt();
    status = ((uint32_t) acts << 16);

    if ((status != status_last) || (rtca_time.min % 10 == 0)) {
    //if (true) {

        FRESULT rc;
        f_mount(0, &fatfs);

        //opt_power_enable();
        //timer_a0_delay(50000);
        disk_initialize(0);

        rc = detectCard();

        if (rc) {
            uint16_t bw;
            f_opendir(&dir, "/");
            snprintf(str_temp, 5, "%d", rtca_time.year);
            rc = f_mkdir(str_temp);
            if ((rc == FR_OK) || (rc == FR_EXIST)) {
                snprintf(str_temp, 9, "/%d/%02d", rtca_time.year, rtca_time.mon);
                rc = f_open(&f, str_temp, FA_WRITE | FA_OPEN_ALWAYS);
                if (!rc) {
                    f_lseek(&f, f_size(&f));
                    //20130620 07:12 -12.2 -34.5 12.30 13.40 1.22 0xffffDA0//53
                    snprintf(str_temp, 53,
                             "%04d%02d%02d %02d:%02d % 2d.%1d % 2d.%1d %02d.%02d %02d.%02d %01d.%02d 0x%04x\r\n",
                             rtca_time.year, rtca_time.mon, rtca_time.day,
                             rtca_time.hour, rtca_time.min,
                             (uint16_t) t_int / 10, (uint16_t) t_int % 10,
                             (uint16_t) t_th / 10, (uint16_t) t_th % 10,
                             (uint16_t) v_bat / 100, (uint16_t) v_bat % 100,
                             (uint16_t) v_pv / 100, (uint16_t) v_pv % 100,
                             (uint16_t) i_ch / 100, (uint16_t) i_ch % 100, 
                             acts);
                    f_write(&f, str_temp, strlen(str_temp), &bw);
                    f_close(&f);
                    uart_tx_str(str_temp, strlen(str_temp));
                } else {
                    die(2, rc);
                }
            } else {
                die(3, rc);
            }
        } else {
            die(1, rc);
        }
        f_mount(0, NULL);
        SDCard_end();
        opt_power_disable();
        status_last = status;
    }
}
#endif                          // !CALIBRATION

void check_ir(void)
{
    if (ir_decode(&results)) {
        sprintf(str_temp, "%ld\r\n", results.value);
        uart_tx_str(str_temp, strlen(str_temp));
        ir_resume();            // Receive the next value
    }
}
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

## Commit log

2013-06-08 calculate resistor dividers and XT1, XT2 load caps
    [sc.brd, sc.sch]
2013-06-08 add firmware
    [adc_calibration.xls]
2013-06-10 relay tests
    [adc_calibration.xls]
2013-06-11 ADC is working. WEEEEEE!
2013-06-17 less code when coin cell power is used
2013-06-18 add ADC calibration mode
    [adc_calibration.xls]
2013-07-28 use different p-mosfet
    [sc.brd, sc.sch]
2013-07-28 save status to sd-card only if relays activate
2013-10-24 review part values
    [sc.brd, sc.sch]
2013-10-26 resistor tweaks
    [sc.brd, sc.sch]
2013-10-26 resistor value tweaks
    [sc.brd, sc.sch]
2013-10-26 switch to hardware rev 03
    [adc_calibration.xls]
2013-10-27 lower LED power
    [sc.brd, sc.sch]
2013-10-27 int temp calibration
    [adc_calibration.ods]
2013-10-29 keep track of programming time
    [sc.brd, sc.sch]
2013-11-23 add charging info
2013-11-24 fix ADC REFVSEL bug
    [adc.c]
2013-11-25 switched to FatFs R0.10
2013-11-25 fix charge_enabled graph
2013-11-28 allow negative temperatures
2015-10-26 add rev2
    [adc_calibration.ods, notes.ods, options.ods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]
2015-10-27 rev2 routing 2/3
    [sc.brd, sc.sch]
2015-11-01 board ready
    [sc.brd, sc.sch]
2015-11-10 fw rev2
    [adc_calibration.ods, notes.ods, options.ods]
2021-05-21 rewritten parts of the rev4 code to compile with gcc 9.2.0
    [adc_calibration.ods, sc.brd, sc.sch]
2021-08-01 control pins working
    [sc.brd, sc.sch]
2021-08-15 adc, rtc work
    [calc.ods, sc.brd, sc.sch]
2021-08-16 timer_a2 and scheduling
2021-08-16 testing stage
    [sc.brd, sc.sch]
2021-08-17 add README files
    [sc.brd, sc.sch]
2022-01-12 uart interface changes needed by latest atlas430

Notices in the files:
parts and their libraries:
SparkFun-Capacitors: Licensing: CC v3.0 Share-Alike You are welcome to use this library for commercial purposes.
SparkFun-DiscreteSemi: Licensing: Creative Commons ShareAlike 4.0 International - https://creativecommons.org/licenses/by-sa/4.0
